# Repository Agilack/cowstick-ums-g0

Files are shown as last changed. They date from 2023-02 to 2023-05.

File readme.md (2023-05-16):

Cowstick UMS
============

The goal of this usb-key is to offer a versatile and customisable mass storage
device. It is *not* desined for very large storage capacity or high throughput
but offer a simple solution to create a storage device with custom features.
This device is part of cowstick boards family.

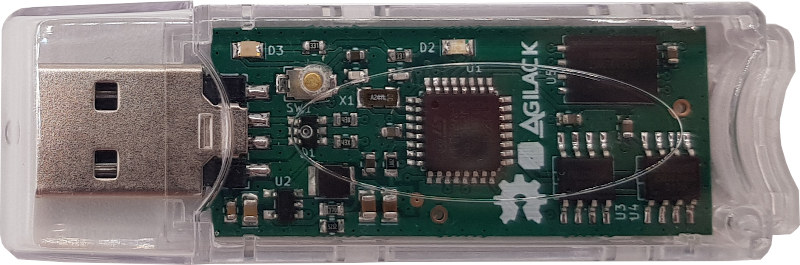
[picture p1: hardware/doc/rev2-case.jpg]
Picture of rev2


CAD sources
-----------

This board has been designed using KiCad EDA (version 6). All sources files
(schematics, routing, ...) are available into the `hardware` folder.

<table>
<tr>
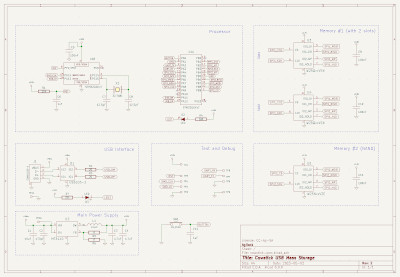
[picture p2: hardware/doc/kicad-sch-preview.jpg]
KiCad schematics
<td></td>
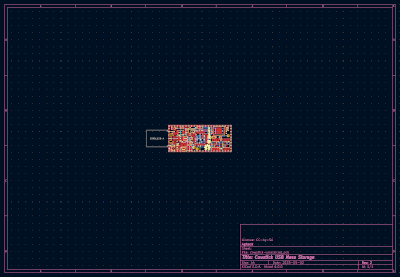
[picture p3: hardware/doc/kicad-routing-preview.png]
KiCad routing
<td></td>
</tr><tr>
<td>Fig1: Preview of the KiCad schematics</td>
<td>Fig2: Preview of the KiCad routing</td>
</tr>
</table>

License
-------

This project is OpenHardware. The hardware stuff is published under terms of
the Creative Commons ShareAlike license (CC-by-SA) see [hardware/License.md](hardware/License.md).
The embedded firmware is published under terms of the GNU Lesser General Public
License (LGPL) version 3 see [firmware/License.md](firmware/License.md).

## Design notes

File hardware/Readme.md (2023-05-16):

Cowstick UMS - Hardware
=======================

A new revision (rev2) have been designed to include some improvements.

List of changes since previous version :
 - Modify power supply to use another regulator ic (see [test_mt3410.md](test_mt3410.md) )
 - Remove the alternative power supply (LDO, never used)
 - Add a second LED indicator and a user push-button
 - Modify the USB connector (for test)

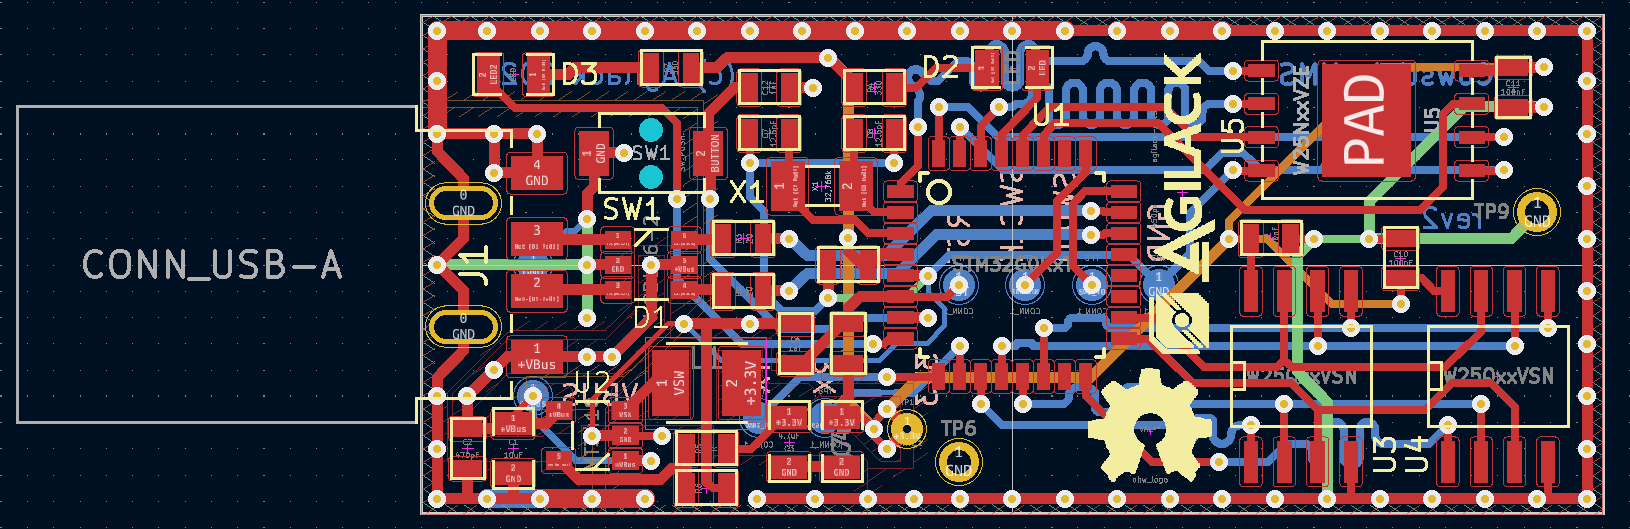
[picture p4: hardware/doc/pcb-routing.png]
PCB Routing


<table>
<tr>
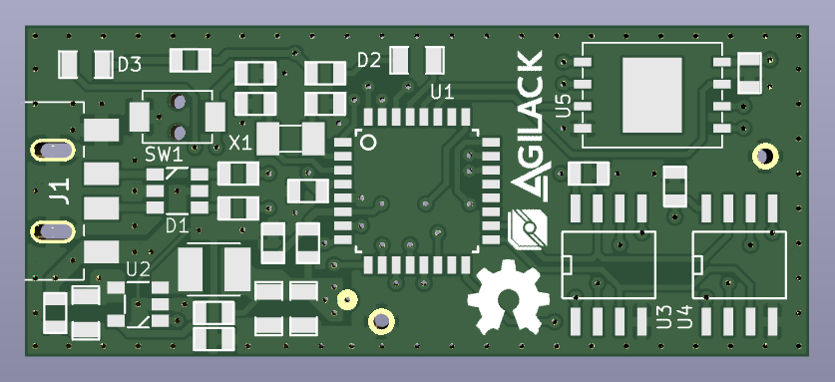
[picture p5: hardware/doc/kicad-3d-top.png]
<td></td>
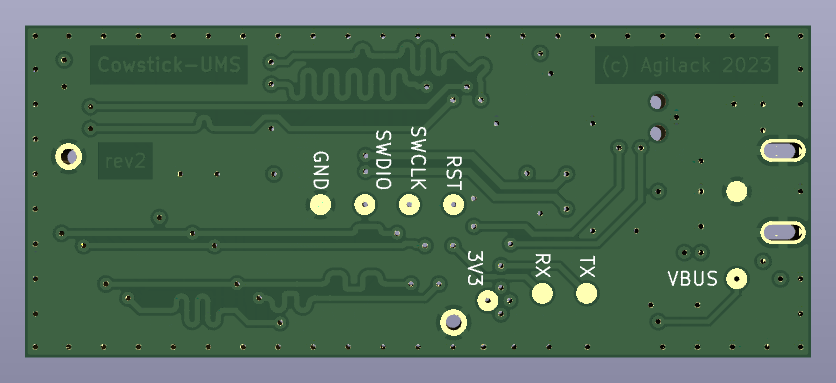
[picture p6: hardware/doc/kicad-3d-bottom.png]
3D view (bottom side)
<td></td>
</tr><tr>
<td>Fig1: 3D view of the top side</td>
<td>Fig2: 3D view of the bottom side</td>
</tr>
</table>

Revision 1
----------

Below pictures of the first revision of the board. Everything works fine, this
revision can still been used.

<table>
<tr>
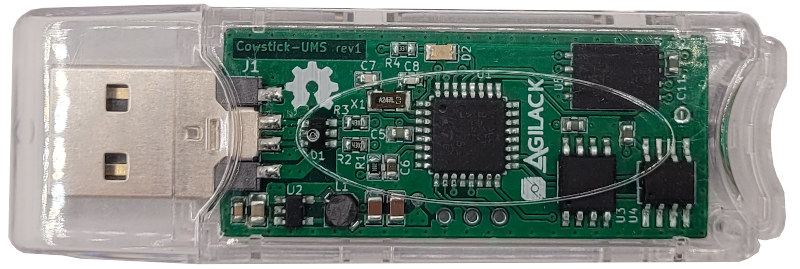
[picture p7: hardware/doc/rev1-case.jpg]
Revision 1
<td></td>
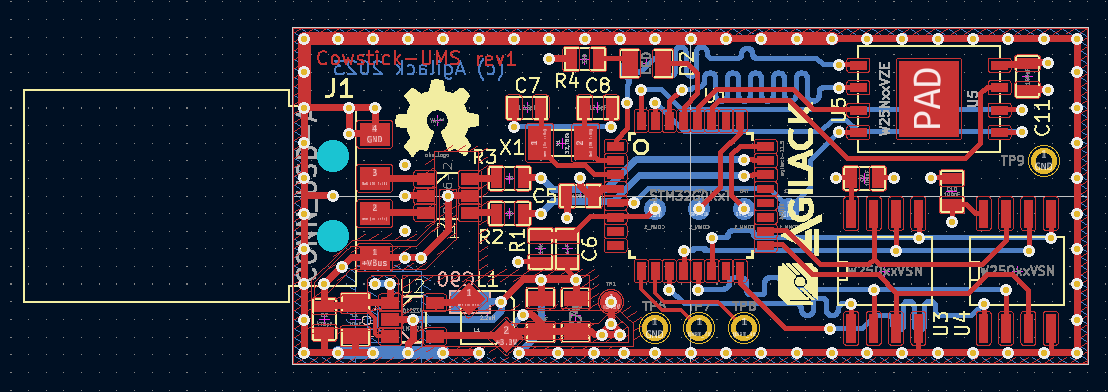
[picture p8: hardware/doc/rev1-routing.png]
Routing of rev1
<td></td>
</tr><tr>
<td>Fig3: cowstick-ums revision 1</td>
<td>Fig4: Preview of rev1 routing</td>
</tr>
<tr>
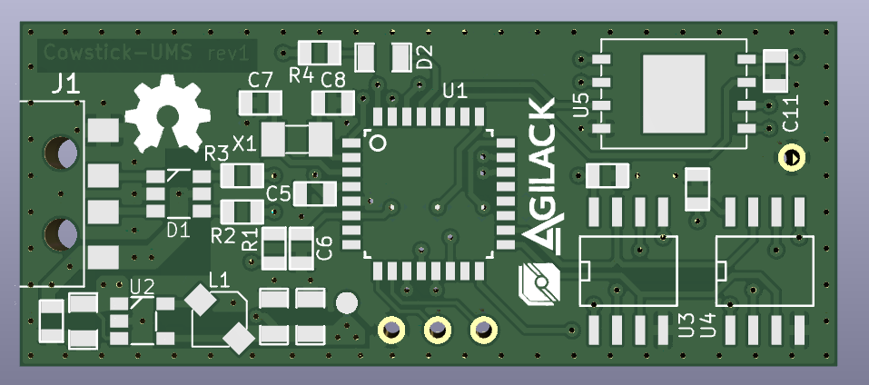
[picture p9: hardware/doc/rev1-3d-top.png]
<td></td>
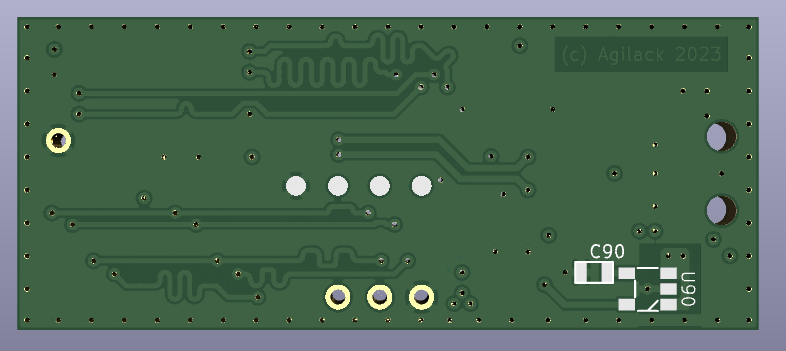
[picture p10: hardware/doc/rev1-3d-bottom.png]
3D view (bottom side)
<td></td>
</tr><tr>
<td>Fig5: 3D view of the top side</td>
<td>Fig6: 3D view of the bottom side</td>
</tr>
</table>

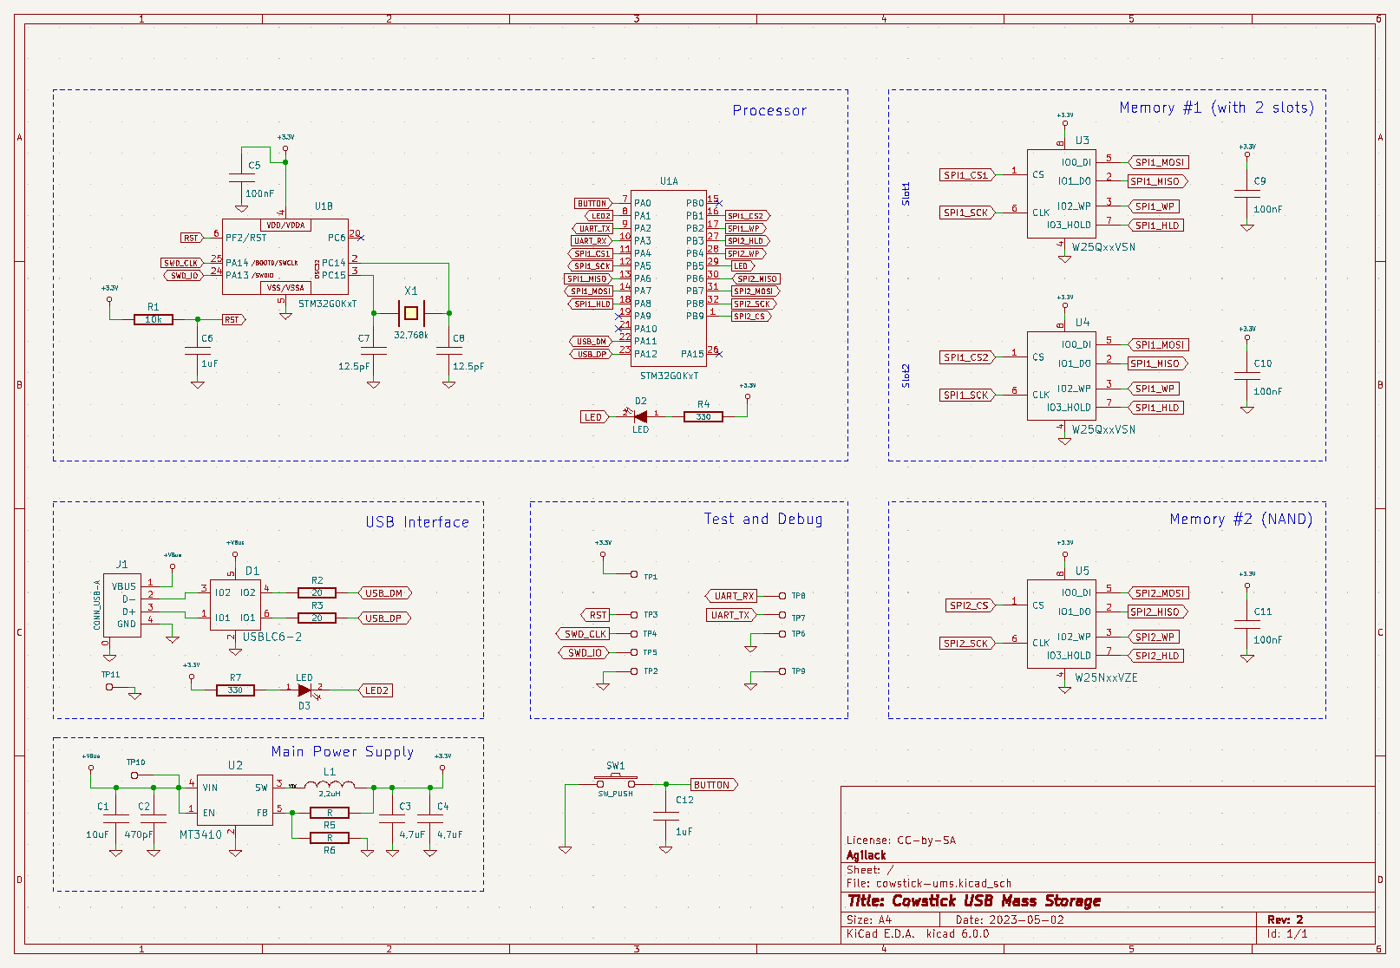
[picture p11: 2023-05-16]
hardware/doc/kicad-sch-large.png

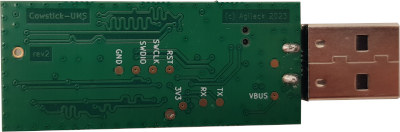
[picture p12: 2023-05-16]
hardware/doc/rev2-bottom.jpg

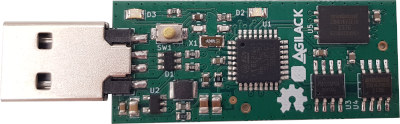
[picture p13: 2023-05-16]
hardware/doc/rev2-top.jpg

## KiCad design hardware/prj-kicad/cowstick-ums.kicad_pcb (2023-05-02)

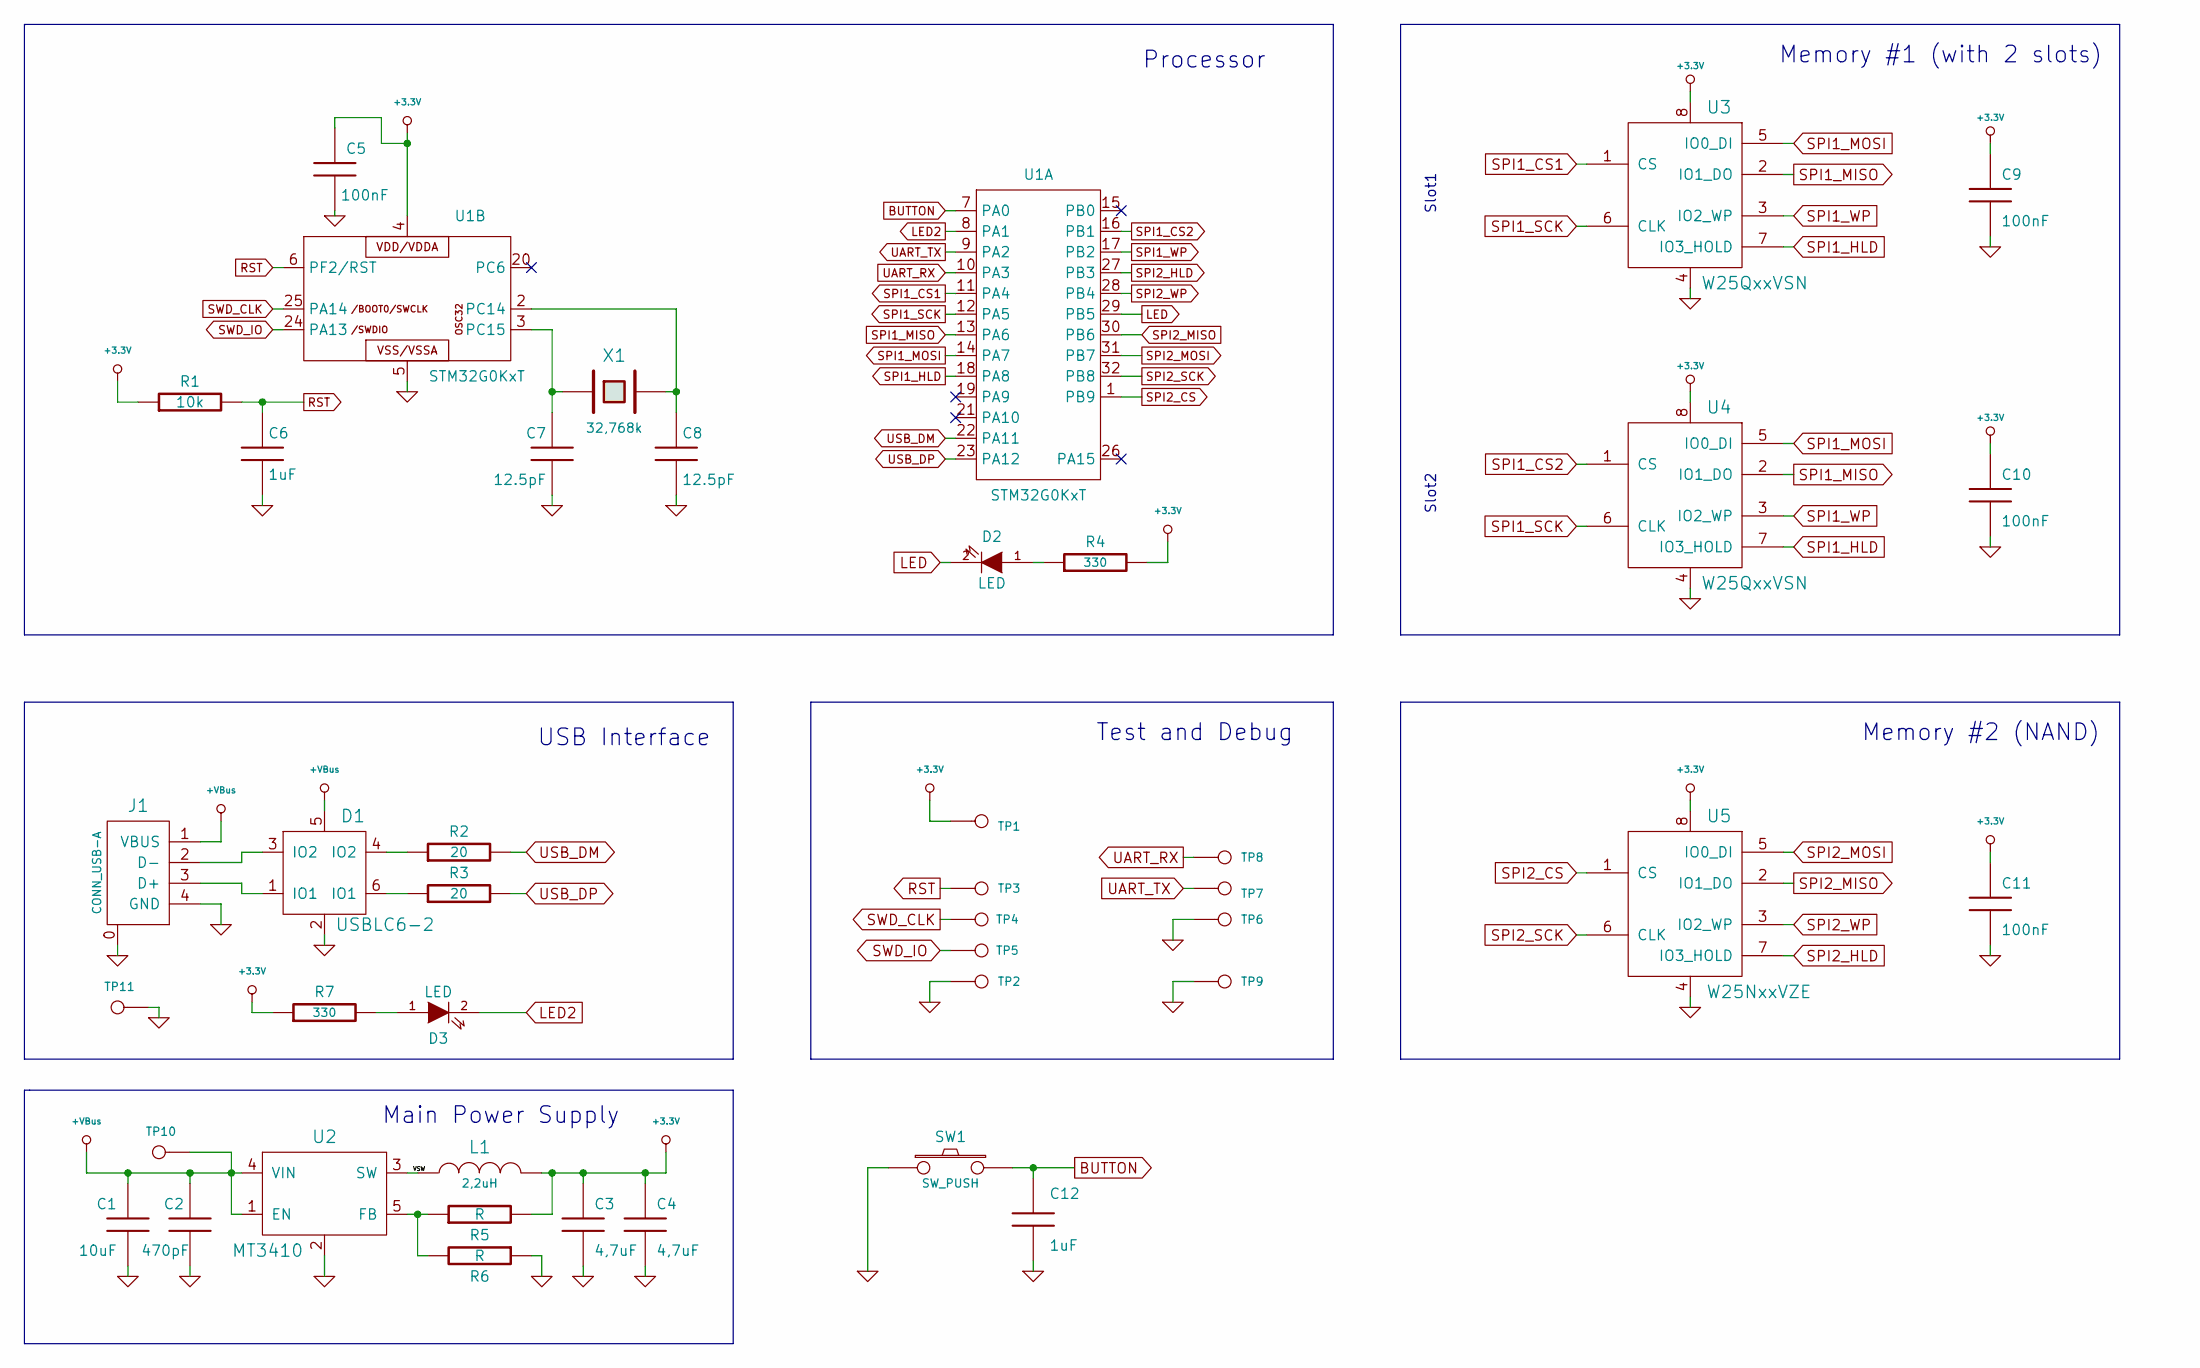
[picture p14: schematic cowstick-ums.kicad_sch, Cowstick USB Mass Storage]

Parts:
C1: 10uF; C_0805
C2: 470pF; C_0603
C3, C4: 4,7uF; C_0805
C5, C9, C10, C11: 100nF; C_0603
C6, C12: 1uF; C_0603
C7, C8: 12.5pF; C_0603
D1: USBLC6-2; SOT23-6
D2, D3: LED; C_0805
J1: CONN_USB-A; CONN_AM90YC
L1: 2,2uH; I_SMD_3x3
R1: 10k; R_0603
R2, R3: 20; R_0603
R4, R7: 330; R_0603
R5, R6: R; R_0603
SW1: SW_PUSH; BUT_TC029
TP1: CONN_1; TP_SMD2
TP2, TP3, TP4, TP5, TP7, TP8, TP10, TP11: CONN_1; TP_SMD
TP6, TP9: CONN_1; TP_PIN
U1: STM32G0KxT; TQFP32
U2: MT3410; SOT23-5
U3, U4: W25QxxVSN; SOIC-8
U5: W25NxxVZE; WSON8
X1: 32,768k; Q_3.2x1.5

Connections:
+3.3V: C3.1, C4.1, C5.1, C9.1, C10.1, C11.1, L1.2, R1.1, R4.2, R5.2, R7.1, TP1.1, U1.4, U3.8, U4.8, U5.8
+VBus: C1.1, C2.1, D1.5, J1.1 (VBUS), TP10.1, U2.1 (EN), U2.4 (VIN)
/VSW: L1.1, U2.3 (SW)
BUTTON: C12.1, SW1.2, U1.7 (PA0)
GND: C1.2, C2.2, C3.2, C4.2, C5.2, C6.2, C7.2, C8.2, C9.2, C10.2, C11.2, C12.2, D1.2, J1.0, J1.4 (GND), R6.1, SW1.1, TP2.1, TP6.1, TP9.1, TP11.1, U1.5, U2.2, U3.4, U4.4, U5.4
LED: D2.2 (K), U1.29 (PB5)
LED2: D3.2 (K), U1.8 (PA1)
unnamed: C7.1, U1.3 (PC15), X1.1
unnamed: C8.1, U1.2 (PC14), X1.2
unnamed: D1.1 (IO1), J1.3 (D+)
unnamed: D1.3 (IO2), J1.2 (D-)
unnamed: D1.4 (IO2), R2.1
unnamed: D1.6 (IO1), R3.1
unnamed: D2.1 (A), R4.1
unnamed: D3.1 (A), R7.2
unnamed: R5.1, R6.2, U2.5 (FB)
RST: C6.1, R1.2, TP3.1, U1.6 (PF2/RST)
SPI1_CS1: U1.11 (PA4), U3.1 (CS)
SPI1_CS2: U1.16 (PB1), U4.1 (CS)
SPI1_HLD: U1.18 (PA8), U3.7 (IO3_HOLD), U4.7 (IO3_HOLD)
SPI1_MISO: U1.13 (PA6), U3.2 (IO1_DO), U4.2 (IO1_DO)
SPI1_MOSI: U1.14 (PA7), U3.5 (IO0_DI), U4.5 (IO0_DI)
SPI1_SCK: U1.12 (PA5), U3.6 (CLK), U4.6 (CLK)
SPI1_WP: U1.17 (PB2), U3.3 (IO2_WP), U4.3 (IO2_WP)
SPI2_CS: U1.1 (PB9), U5.1 (CS)
SPI2_HLD: U1.27 (PB3), U5.7 (IO3_HOLD)
SPI2_MISO: U1.30 (PB6), U5.2 (IO1_DO)
SPI2_MOSI: U1.31 (PB7), U5.5 (IO0_DI)
SPI2_SCK: U1.32 (PB8), U5.6 (CLK)
SPI2_WP: U1.28 (PB4), U5.3 (IO2_WP)
SWD_CLK: TP4.1, U1.25 (PA14)
SWD_IO: TP5.1, U1.24 (PA13)
UART_RX: TP8.1, U1.10 (PA3)
UART_TX: TP7.1, U1.9 (PA2)
USB_DM: R2.2, U1.22 (PA11)
USB_DP: R3.2, U1.23 (PA12)

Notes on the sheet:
Memory #2 (NAND)
Memory #1 (with 2 slots)
Test and Debug
Slot1
Slot2
Main Power Supply
Processor
USB Interface

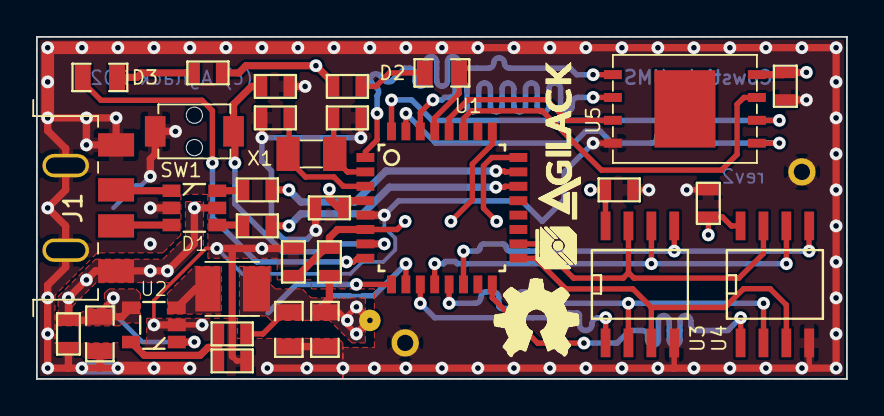
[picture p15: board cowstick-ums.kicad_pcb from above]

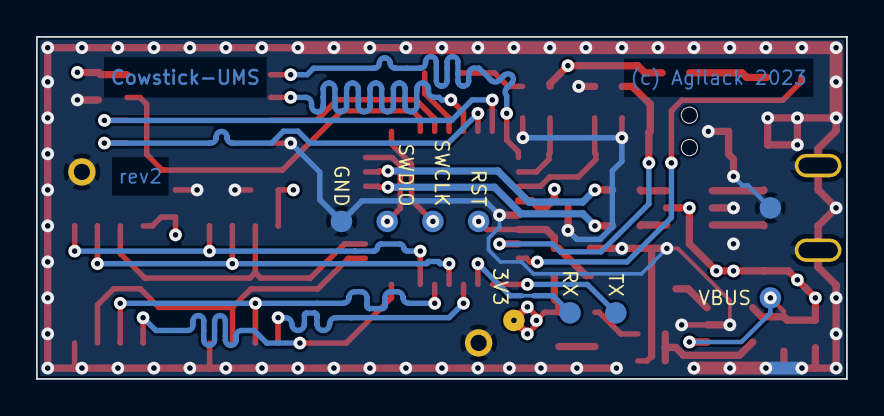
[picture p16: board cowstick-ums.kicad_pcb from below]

Board: 4 copper layers, 45.0 x 19.0 mm, 44 parts (8 on the bottom side), 36 nets.

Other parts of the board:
agilack-11.5: 450px; logo-agilack-11.5
ohw_logo: VAL**; logo-ohw

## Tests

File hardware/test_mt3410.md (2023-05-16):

Test of MT3410 power supply
===========================

The goal of this test is to check performance of the MT3410 power supply
used into board rev2.

For this test, a board has been mounted with power supply only. The input has
been connected to a 5V regulated power supply, and for the load a variable
resistance has been connected on output.

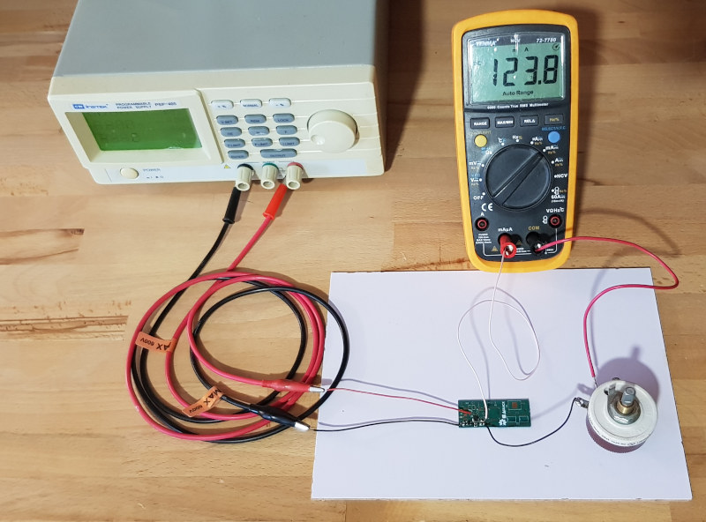
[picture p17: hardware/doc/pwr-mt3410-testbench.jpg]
MT3410 testbench


Measures
--------

<table>
<tr><td><b>U In</b></td><td><b>I In</b></td><td><b>U Out</b></td><td><b>IOut</b></td>  <td><b>Ripple Out</b></td></tr>
<tr><td>5,00</td> <td>86 mA</td><td>3,34</td><td>120,9 mA</td><td>20mV @ 1,15MHz</td></tr>
<tr><td>5,00</td><td>106 mA</td><td>3,32</td><td>150,1 mA</td><td>22mV @ 1,15MHz</td></tr>
<tr><td>5,00</td><td>141 mA</td><td>3,31</td><td>198,9 mA</td><td>26mV @ 1,15MHz</td></tr>
<tr><td>5,00</td><td>179 mA</td><td>3,32</td><td>251,8 mA</td><td>27mV @   ''   </td></tr>
<tr><td>5,00</td><td>212 mA</td><td>3,31</td><td>298,2 mA</td><td>&nbsp;</td></tr>
<tr><td>5,00</td><td>249 mA</td><td>3,31</td><td>349,3 mA</td><td>&nbsp;</td></tr>
<tr><td>5,00</td><td>289 mA</td><td>3,30</td><td>403,4 mA</td><td>&nbsp;</td></tr>
<tr><td>5,00</td><td>324 mA</td><td>3,29</td><td>449,5 mA</td><td>&nbsp;</td></tr>
<tr><td>5,00</td><td>362 mA</td><td>3,28</td><td>502,0 mA</td><td>&nbsp;</td></tr>
</table>

<table>
<tr>
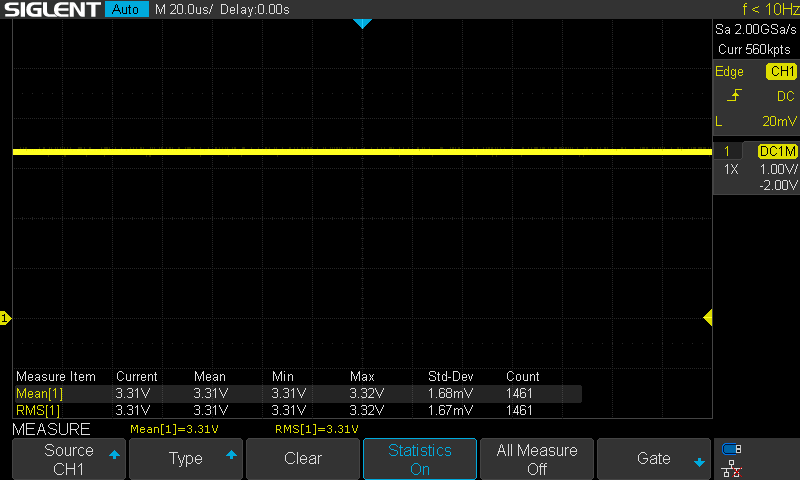
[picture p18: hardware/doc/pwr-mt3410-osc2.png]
DC at 200mA
<td></td>
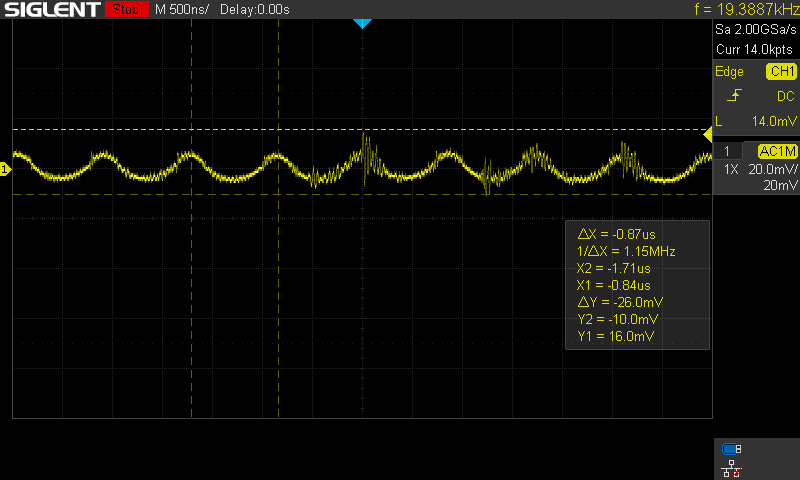
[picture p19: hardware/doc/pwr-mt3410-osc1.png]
Noise at 100mA
<td></td>
</tr><tr>
<td>Fig2: Output with 200mA load</td>
<td>Fig3: Noise with 100mA load</td>
</tr>
<tr>
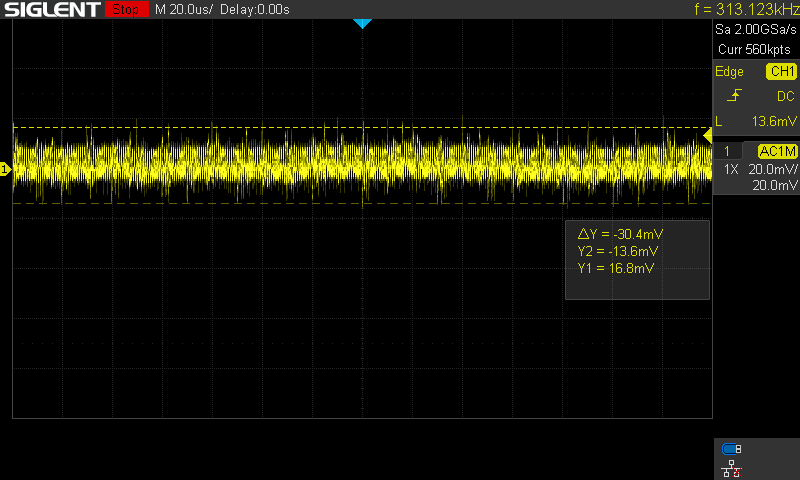
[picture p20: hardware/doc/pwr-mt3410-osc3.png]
Noise 300mA
<td></td>
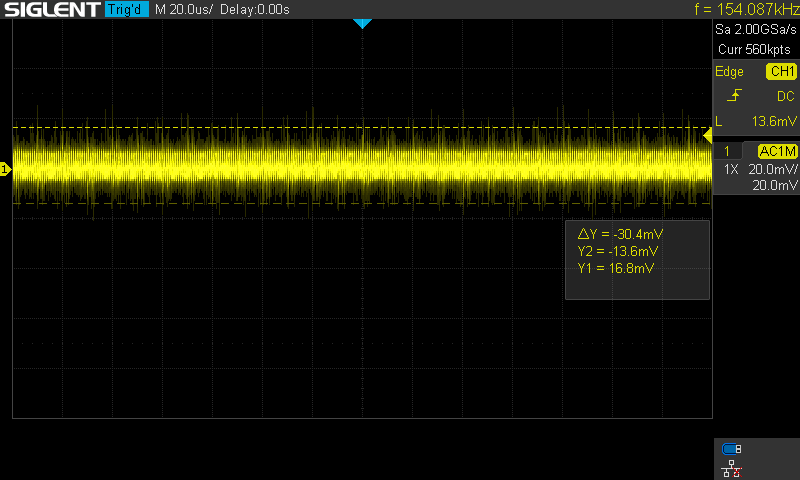
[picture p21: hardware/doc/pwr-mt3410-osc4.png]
Noise 400mA
<td></td>
</tr><tr>
<td>Fig4: Noise with 300mA load</td>
<td>Fig5: Noise with 400mA load</td>
</tr>
</table>

Thermal test
------------

A quick thermal verification has been made. Below picture has been taken
after 15 minutes at 200mA (T amb ~19°C). A more complete and documented
thermal test should be made (but not yet planned)

<table>
<tr>
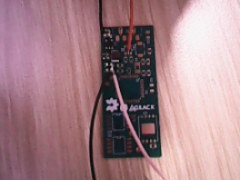
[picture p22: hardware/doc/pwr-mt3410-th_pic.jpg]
Camera view
<td></td>
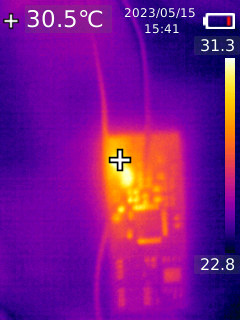
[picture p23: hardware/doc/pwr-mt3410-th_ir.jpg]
IR view
<td></td>
</tr><tr>
<td>Fig6: Camera view</td>
<td>Fig7: IR view</td>
</tr>
</table>

Conclusion
----------

The new regulator ic MT3410 seems to be ok for the needs of cowstick-ums.

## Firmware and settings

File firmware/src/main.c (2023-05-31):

/**
 * @file  main.c
 * @brief Entry point of the firmware and main application loop
 *
 * @author Saint-Genest Gwenael <gwen@cowlab.fr>
 * @copyright Agilack (c) 2023
 *
 * @page License
 * Cowstick-UMS firmware is free software: you can redistribute it and/or
 * modify it under the terms of the GNU Lesser General Public License
 * version 3 as published by the Free Software Foundation. You should have
 * received a copy of the GNU Lesser General Public License along with this
 * program, see LICENSE.md file for more details.
 * This program is distributed WITHOUT ANY WARRANTY.
 */
#include "app.h"
#include "hardware.h"
#include "libc.h"
#include "log.h"
#include "mem.h"
#include "scsi.h"
#include "spi.h"
#include "time.h"
#include "uart.h"
#include "usb.h"
#include "usb_msc.h"
#include "driver/flash_mcu.h"

void test_mem(void);
void test_flash_mcu(void);

/**
 * @brief Entry point of the C code
 *
 */
int main(void)
{
	u32  tm;
	uint i;

	/* Initialize low-level hardware */
	hw_init();
	time_init();
	/* Initialize peripherals */
	uart_init();
	spi_init();
	usb_init();

	log_print(0, "--=={ Cowstick UMS }==--\r\n");

	/* Initialize libraries */
	log_init();
	mem_init();
	scsi_init();
	usb_msc_init();

#ifdef TEST_FLASH_MCU
	test_flash_mcu();
#endif
	/* Initialize and start custom app (if any) */
	app_init();

	/* Insert an empry log line after end of inits */
	log_print(LOG_INF, "\n");

	mem_detect();
	for (i = 0; i < MEM_NODE_COUNT; i++)
	{
		mem_node *node = mem_get_node(i);
		if (node == 0)
			break;
		log_print(LOG_INF, "Memory slot #%d : ", i);
		if (node->type == 0)
			log_print(LOG_INF, "Empty\n");
		else if (node->type == 1)
		{
			const mem_flash_chip *fc;
			fc = (const mem_flash_chip *)node->chip;
			log_print(LOG_INF, "FLASH %s\n", fc->name);
		}
	}
#ifdef TEST_MEM
	test_mem();
#endif

	/* Start USB device */
	usb_start();

	tm = time_now(0);

	/* Main firmware loop */
	while(1)
	{
		usb_periodic();

		app_periodic();

		/* Blink led1 */
		if (time_since(tm) > 400)
		{
			if (reg_rd(GPIOB + 0x10) & (1 << 5))
				/* Set LED on */
				reg_wr(GPIOB + 0x18, (1 << 21));
			else
				/* Set LED off */
				reg_wr(GPIOB + 0x18, (1 << 5));
			tm = time_now(0);
		}
	}
}

#ifdef TEST_MEM
void test_mem(void)
{
	mem_node *node = mem_get_node(0);
	uint i;

	log_print(0, "read() result=%d\n",
	    (uint)mem_read(0, 0x000000, 512, 0) );
	log_dump(node->cache_buffer, 64, 2);

	memset(node->cache_buffer, 0, 4096);
	mem_write(0, 0x000000, 512, 0);

	log_print(0, "read() result=%d\n",
	    (uint)mem_read(0, 0x000000, 512, 0) );
	log_dump(node->cache_buffer, 64, 2);

	for (i = 0; i < 16; i++)
	{
		if (i & 1)
			node->cache_buffer[i] = 0x55;
		else
			node->cache_buffer[i] = 0xAA;
	}
	mem_write(0, 0x000000, 512, 0);

	log_print(0, "read() result=%d\n",
	    (uint)mem_read(0, 0x000000, 512, 0) );
	log_dump(node->cache_buffer, 64, 2);

	mem_erase(0, 0x000000, 512);

	log_print(0, "read() result=%d\n",
	    (uint)mem_read(0, 0x000000, 512, 0) );
	log_dump(node->cache_buffer, 64, 2);
	while(1);
}
#endif

#ifdef TEST_FLASH_MCU
void test_flash_mcu(void)
{
	u8 buffer[256];
	u32 addr, v;
	int i;

	log_print(LOG_DBG, "Test: Dump initial flash content (bank2) :\n");
	log_dump((u8 *)0x08020000, 64, 1);

	log_print(LOG_DBG, "\nTest: Erase first page of bank2 ...\n");
	flash_mcu_erase(0x08020000);
	for (addr = 0x08020000; addr < 0x08020800; addr += 4)
	{
		v = *(u32 *)addr;
		if (v != 0xFFFFFFFF)
		{
			log_print(LOG_DBG, "Test: %{Erase failed%} at %32x readed %32x\n", 1, addr, v);
			break;
		}
	}
	if (addr == 0x08020800)
		log_print(LOG_DBG, "Test: Page erase %{success%}\n", 2);

	log_print(LOG_DBG, "\nTest: Write content to page\n");
	// Prepare bufffer with values
	for (i = 0; i < 0xFF; i++)
		buffer[i] = (u8)(i & 0xFF);
	// Write this test pattern to the whole page
	for (addr = 0x08020000; addr < 0x08020800; addr += 256)
		flash_mcu_write(addr, buffer, 256);
	// Try to read back and verify
	for (addr = 0x08020000; addr < 0x08020800; addr++)
	{
		v = *(u8 *)addr;
		if (v != (addr & 0xFF))
		{
			log_print(LOG_DBG, "Test: %{Write failed%} at %32x : expected %8x but readed %8x\n", 1, addr, (addr & 0xFF), v);
			break;
		}
	}
	if (addr == 0x08020800)
		log_print(LOG_DBG, "Test: Page erase %{success%}\n", 2);

	log_print(LOG_DBG, "\nTest: Dump initial flash content (bank1) :\n");
	log_dump((u8 *)0x08010000, 512, 1);

	//flash_mcu_erase(0x08010000);
	//flash_mcu_erase(0x0801F800);
	//flash_mcu_erase(0x0803F800);
	//while(1);
	uart_flush();
}
#endif
/* EOF */

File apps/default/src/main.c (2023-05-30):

/**
 * @file  main.c
 * @brief Entry point of the firmware and main application loop
 *
 * @author Saint-Genest Gwenael <gwen@cowlab.fr>
 * @copyright Agilack (c) 2023
 *
 * @page License
 * Cowstick-UMS firmware is free software: you can redistribute it and/or
 * modify it under the terms of the GNU Lesser General Public License
 * version 3 as published by the Free Software Foundation. You should have
 * received a copy of the GNU Lesser General Public License along with this
 * program, see LICENSE.md file for more details.
 * This program is distributed WITHOUT ANY WARRANTY.
 */
#include "log.h"
#include "mem.h"
#include "scsi.h"
#include "time.h"

#undef SCSI_DEBUG_READ

#define API_BASE 0x080000D0

static void api_init(void);
int scsi_rd(u32 addr, u32 len, u8 *data);
int scsi_vendor(lun *unit, u32 *ctx, u8 *cb, uint len);

static u32 tm_ref;

/**
 * @brief App initialization handler
 *
 * This function is referenced into application vector table and called by
 * the main firmware on startup. It is always the first application function
 * called.
 */
int app_init(void)
{
	lun *unit;

	api_init();

	unit = scsi_lun_get(0);
	/* Configure lun callbacks */
	unit->rd         = scsi_rd;
	unit->cmd_vendor = scsi_vendor;
	/* Initialize lun format */
	unit->capacity = 131072;
	unit->state    = 1;
	unit->writable = 0;

	log_print(LOG_INF, "APP: Default app initialized %32x\n", unit);
	tm_ref = time_now(0);

	// Success
	return(0);
}

/**
 * @brief App periodic process
 *
 * This function is referenced into application vector table and called by
 * the main firmware on each cycle of the main firmware loop to do periodic
 * stuff.
 */
void app_periodic(void)
{
	if (time_since(tm_ref) > 4000)
	{
		log_print(LOG_DBG, "APP: %{Periodic BEEP :p%}\n", LOG_BCYN);
		tm_ref = time_now(0);
	}
}

/**
 * @brief App reset
 *
 * This function is referenced into application vector table and called by
 * the main firmware when USB device is reset.
 */
void app_reset(void)
{
	log_print(LOG_DBG, "APP: %{Reseted%}\n", LOG_YLW);
}

/**
 * @brief Read function for the LUN
 *
 * This function is registered as read handler for the SCSI lun 0 and called
 * by the SCSI layer when a read request is received.
 *
 * @param addr Address to read
 * @param len  Number of byte to read
 * @param data Pointer to a buffer where readed data can be stored
 * @return integer Number of readed bytes
 */
int scsi_rd(u32 addr, u32 len, u8 *data)
{
	if (len > 512)
		len = 512;

#ifdef SCSI_DEBUG_READ
	log_print(LOG_DBG, "APP: SCSI Read %d bytes at 0x%32x\n", len, addr);
#endif

	mem_read(0, addr, len, data);

	return((int)len);
}

/**
 * @brief Handle a vendor command for the LUN
 *
 * This function is registered as a callback for SCSI lun 0 and is called by
 * the SCSI layer when a vendor command (group 6 or group7) is received.
 *
 * @param unit Pointer to the LUN structure where command has been received
 * @param ctx Pointer to a "context" variable used to track transactions
 * @param cb  Pointer to the received command block
 * @param len Length of the received command
 * @return integer Result of the command.
 */
int scsi_vendor(lun *unit, u32 *ctx, u8 *cb, uint len)
{
	(void)unit;
	(void)ctx;
	(void)len;

	log_print(LOG_DBG, "APP: SCSI vendor command %8x\n", cb[0]);
	return(0);
}

/* API functions used by the app */
void (*log_print)(uint level, const char *s, ...);
u32  (*time_now)(tm_t *timeval); 
int  (*time_since)(u32 ref);
int  (*mem_read) (uint nid, u32 addr, uint len, u8 *buffer);
lun *(*scsi_lun_get)(int pos);

/**
 * @brief Initialize API mapped functions
 *
 * This function read tables of firmware exposed functions and initialize
 * function pointers accordingly.
 */
static void api_init(void)
{
	u32 t_addr;

	t_addr = *(u32*)(API_BASE + 0x08);
	time_now   = (u32(*)(tm_t *))(*(u32*)(t_addr+0x00));
	time_since = (int(*)(u32))   (*(u32*)(t_addr+0x04));
	t_addr = *(u32*)(API_BASE + 0x0C);
	log_print = (void(*)(uint,const char *,...))(*(u32*)(t_addr+0x1C));
	t_addr = *(u32*)(API_BASE + 0x10);
	mem_read = (int(*)(uint,u32,uint,u8*))(*(u32*)(t_addr+0x04));
	t_addr = *(u32*)(API_BASE + 0x14);
	scsi_lun_get = (lun*(*)(int))(*(u32*)(t_addr + 0x00));
}
/* EOF */

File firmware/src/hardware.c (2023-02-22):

/**
 * @file  hardware.c
 * @brief Low-level cowstick-ums hardware configuration
 *
 * @author Saint-Genest Gwenael <gwen@cowlab.fr>
 * @copyright Agilack (c) 2023
 *
 * @page License
 * Cowstick-UMS firmware is free software: you can redistribute it and/or
 * modify it under the terms of the GNU Lesser General Public License
 * version 3 as published by the Free Software Foundation. You should have
 * received a copy of the GNU Lesser General Public License along with this
 * program, see LICENSE.md file for more details.
 * This program is distributed WITHOUT ANY WARRANTY.
 */
#include "hardware.h"

static inline void _init_clocks(void);
static inline void _init_led(void);
static inline void _init_spi(void);
static inline void _init_uart(void);
static inline void _init_usb(void);

/**
 * @brief Initialize processor, clocks and some peripherals
 *
 * This function should be called on startup for clocks and IOs configuration.
 */
void hw_init(void)
{
	int i;

	/* RCC : Activate GPIOA and GPIOB */
	reg_wr(RCC_IOPENR, (1 << 1) | (1 << 0));
	/* RCC : Reset GPIOA and GPIOB */
	reg_wr(RCC_IOPRSTR, (1 << 1) | (1 << 0));
	for (i = 0; i < 16; i++)
		asm volatile("nop");
	reg_wr(RCC_IOPRSTR, 0);

	_init_clocks();

	_init_led();
	_init_uart();
	_init_spi();
	_init_usb();
}

/**
 * @brief Configure clocks for main speed operations
 *
 * The clocks are configured as is:
 *   - Processor and SYSCLK run at 64 MHz (using HSI16 and PLL)
 *   - The debug port (USART2) use HSI16
 *   - USB device controller use internal RC oscillator HSI48
 *   - An optional low speed clock for RTC using LSE
 */
static inline void _init_clocks(void)
{
	u32 val;

	/* Set HSI16 as USART2 clock source */
	val = reg_rd(RCC_CCIPR);
	val &= ~(u32)(3 << 2);
	val |=  (u32)(2 << 2);
	reg_wr(RCC_CCIPR, val);

	/* If PLL is used, SYSCLK = 64MHz else SYSCLK = 16 MHz */
#ifdef USE_PLL
	/* Configure PLL */
	val =  (2 << 0);    // PLL clock source = HSI16
	val |= (1 << 4);    // set M (VCO divisor) VCO clock input = 8MHz
	val |= (16 <<  8);  // set N (VCO multiplier) VCO output = 128MHz
	val |= ( 1 << 29);  // set R output divisor, PLLRCLK output = 64MHz
	reg_wr(RCC_PLL_CFGR, val);
	/* Activate PLL and wait for PLL ready */
	reg_set(RCC_CR, (1 << 24));
	while( (reg_rd(RCC_CR) & (1 << 25)) == 0)
		;

	/* Set Flash latency to 2WS */
	reg_set((u32)(FLASH + 0x00), 2); // Flash ACR
	while( (reg_rd(FLASH + 0x00) & 7) != 2)
		;

	/* Enable PLLRCLK */
	reg_set(RCC_PLL_CFGR, (1 << 28));

	/* Change the clock source */
	val  = reg_rd(RCC_CFGR);
	val &= ~(u32)0x07; // Clear System Clock Switch
	val |=  (u32)0x02; // Set PLLRCLK
	reg_wr(RCC_CFGR, val);
#endif

	/* Activate HSI48 RC oscillator */
	reg_set(RCC_CR, (1 << 22));
	while( (reg_rd(RCC_CR) & (1 << 23)) == 0)
		;
	/* Activate CRS */
	reg_set((u32)RCC_APBENR1, (1 << 16));
	/* Reset CRS */
	reg_set((u32)RCC_APBRSTR1, (1 << 16));
	(void)reg_rd((u32)RCC_APBRSTR1);
	reg_clr((u32)RCC_APBRSTR1, (1 << 16));
	/* Configure CRS */
	val = (2 << 28); // SYNC_SRC: USB SOF
	val |= (47999 & 0xFFFF); // Reload value
	val |= ( 22 << 16); // FELIM
	reg_wr(CRS+0x04, val); // CRS_CFGR
	/* Adjust TRIM */
	val = reg_rd(CRS+0x00);
	val &= ~(u32)(0x7F << 8);
	val |=  (u32)(32   << 8);
	reg_wr(CRS+0x00, val);
	/* Enable Auto-Trim and Error counter*/
	reg_set(CRS+0x00, (1 << 6) | (1 << 5));

#ifdef USE_LSE
	/* Activate power controller (PWR) */
	reg_set(RCC_APBENR1, (1 << 28));
	/* Disable RTC domain write protection */
	reg_set(PWR + 0x00, (1 << 8));
	/* Configure LSE drive level */
	reg_set(RCC_BDCR, (3 << 3));
	/* Activate LSE (set LSEON bit) */
	reg_set(RCC_BDCR, (1 << 0));
	for (i = 0; i < 0x100000; i++)
	{
		if (reg_rd(RCC_BDCR) & (1 << 1))
			break;
	}
#endif
}

/**
 * @brief Initialize the IO connected to LED
 *
 */
static inline void _init_led(void)
{
	u32 v;

	/* Use open-drain io for LED */
	reg_wr(GPIO_OTYPER(GPIOB), (1 << 5));
	/* Default state : IO=1 -> LED off */
	reg_wr(GPIO_BSRR(GPIOB),   (1 << 5));
	/* Set PB5 as general purpose output */
	v = reg_rd(GPIO_MODER(GPIOB));
	v &= ~(u32)(3 << 10);
	v |=  (u32)(1 << 10);
	reg_wr(GPIO_MODER(GPIOB), v);
}

/**
 * @brief Initialize the IOs connected to SPI memories
 *
 */
static inline void _init_spi(void)
{
	u32 moder_a, moder_b;
	u32 afrl_a,  afrl_b, afrh_b;
	u32 speed_a, speed_b;

	/* Read all registers that will be modified for SPI ios */
	moder_a = reg_rd(GPIO_MODER(GPIOA));
	moder_b = reg_rd(GPIO_MODER(GPIOB));
	afrl_a  = reg_rd(GPIO_AFRL(GPIOA));
	afrl_b  = reg_rd(GPIO_AFRL(GPIOB));
	afrh_b  = reg_rd(GPIO_AFRH(GPIOB));
	speed_a = reg_rd(GPIO_OSPEEDR(GPIOA));
	speed_b = reg_rd(GPIO_OSPEEDR(GPIOB));

	/* SPI1: Configure Chip Select 1 (PA4) as output */
	reg_wr(GPIO_BSRR(GPIOA), (1 << 4));
	moder_a &= ~(u32)(3 << 8);
	moder_a |=  (u32)(1 << 8);
	/* SPI1: Configure Chip Select 2 (PB1) as output */
	reg_wr(GPIO_BSRR(GPIOB), (1 << 1));
	moder_b &= ~(u32)(3 << 2);
	moder_b |=  (u32)(1 << 2);
	/* SPI2: Configure Chip Select (PB9) as output */
	reg_wr(GPIO_BSRR(GPIOB), (1 << 9));
	moder_b &= ~(u32)(3 << 18);
	moder_b |=  (u32)(1 << 18);
	/* Apply MODER now to force all memory chips to inactive (CS=1) */
	reg_wr(GPIO_MODER(GPIOA), moder_a);
	reg_wr(GPIO_MODER(GPIOB), moder_b);

	/* SPI1: Configure SCK signal (use AF) */
	afrl_a &= ~(u32)(0xF << 20); // Reset PA5 AF to AF0
	moder_a &= ~(u32)(3 << 10);  // Clear PA5 mode
	moder_a |=  (u32)(2 << 10);  // Set mode to Alternate Function
	speed_a |=  (u32)(3 << 10);  // Very High Speed
	/* SPI1: Configure MISO signal (use AF) */
	afrl_a &= ~(u32)(0xF << 24); // Reset PA6 AF to AF0
	moder_a &= ~(u32)(3 << 12);  // Clear PA6 mode
	moder_a |=  (u32)(2 << 12);  // Set mode to Alternate Function
	speed_a |=  (u32)(3 << 12);  // Very High Speed
	/* SPI1: Configure MOSI signal (use AF) */
	afrl_a &= ~(u32)(0xF << 28); // Reset PA7 AF to AF0
	moder_a &= ~(u32)(3 << 14);
	moder_a |=  (u32)(2 << 14);  // Set PA7 mode to Alternate Function
	speed_a |=  (u32)(3 << 14);  // Very High Speed
	/* SPI1: Congigure Hold signal (as GPIO) */
	reg_wr(GPIO_BSRR(GPIOA), (1 << 24));
	moder_a &= ~(u32)(3 << 16);
	moder_a |=  (u32)(1 << 16);  // Set PA8 mode to GP output
	/* SPI1: Configure Write Protect signal (as GPIO) */
	reg_wr(GPIO_BSRR(GPIOB), (1 << 18)); // WP=0 (proction active)
	moder_b &= ~(u32)(3 << 4);
	moder_b |=  (u32)(1 << 4);   // Set PB2 mode to GP output
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

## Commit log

2023-02-03 --=={ Create project }==--
    [cowstick-ums.kicad_pcb, cowstick-ums.kicad_sch]
2023-02-04 Hardware: Improve PCB r1, add MCU (STM32G0)
    [cowstick-ums.kicad_pcb, cowstick-ums.kicad_sch]
2023-02-07 Hardware: Improve PCB r1, add two SOIC8 flash memory ic for channel 1
    [cowstick-ums.kicad_pcb, cowstick-ums.kicad_sch]
2023-02-09 Hardware: Improve PCB r1, add one Nand flash memory for "large" capacity (channel 2)
    [cowstick-ums.kicad_pcb, cowstick-ums.kicad_sch]
2023-02-11 Hardware: Finish and cleanup pcb r1 and create production files
    [cowstick-ums-B_Cu.gbr, cowstick-ums-B_Mask.gbr, cowstick-ums-B_Paste.gbr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]
2023-02-14 Firmware: Create a basic firmware (init hw, uart, and detect memories)
2023-02-16 Firmware: Add clock configuration (PLL and LSE) and scripts for load/debug
    [gdb.cfg]
2023-02-22 Firmware: Create a module for USB device interface (Wip ! incomplete enumeration)
    [gdb.cfg]
2023-02-25 Firmware: Improve USB module, add missing stardard requests, and add device unit-test
    [main.c, usb.c]
2023-03-18 Firmware: Create a dummy BULK interface driver to test data endpoints support
    [gdb.cfg]
2023-03-28 Firmware: Improve USB, add interface driver, improve handle of control requests
2023-04-06 Firmware: Insert an USB Mass Storage class driver (basic support, wip)
    [gdb.cfg]
2023-04-12 Firmware: Improve Mass Storage driver (MSC), all basic features now available
2023-04-14 Firmware: Improve SCSI driver, add more commands and fix access to external flash chip
2023-04-18 Firmware: Improve Mass Storage, add ResetRecovery command and create a unit-test for MSC layer
    [main.cpp, usb.c]
2023-04-22 Firmware: Improve Mass Storage, handle more errors (test the 13 cases of Bulk-Only Transport spec)
    [main.cpp]
2023-05-02 Hardware: Modify PCB for a new revision (rev2) and create production files - Add pushbutton and a second LED - Replace power reg and USB connector with a new refs
    [cowstick-ums-B_Cu.gbr, cowstick-ums-B_Mask.gbr, cowstick-ums-B_Paste.gbr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]
2023-05-31 Firmware: Add a new driver for MCU internal flash memory (erase/write)
2023-06-01 Firmware: Move SCSI read/write buffer to dedicated files, add microcode upgrade
    [gdb_load.cfg]
